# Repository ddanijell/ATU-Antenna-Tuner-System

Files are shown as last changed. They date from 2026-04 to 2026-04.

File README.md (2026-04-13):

# ATU Remote Control System

> HF antenna tuner upgrade — wireless remote control, real-time PWR/SWR telemetry, manual L/C tuning and full touch GUI for ATU100/ATU130.

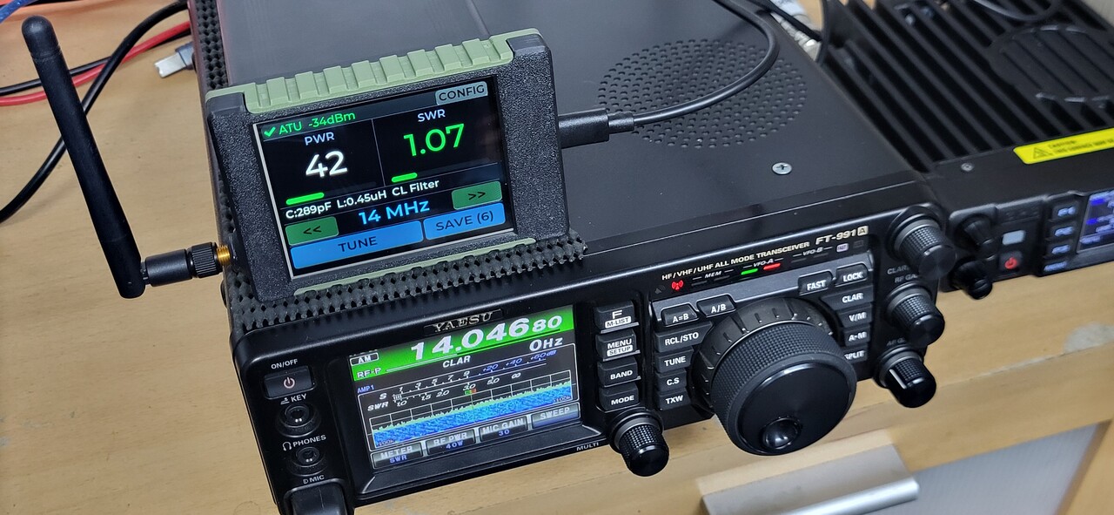
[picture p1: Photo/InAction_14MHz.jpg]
In action — 14 MHz


> More photos available in the [Photo](Photo/) folder.

---

## System Architecture

System block diagram

---

## GUI Screens

| MAIN | CONFIG | BRIGHTNESS | SYSTEM SETTINGS |
|:---:|:---:|:---:|:---:|
|  |  |  |  |

---

## About

This system is an upgrade for the existing [ATU100/ATU130](https://github.com/Dfinitski/N7DDC-ATU-100-mini-and-extended-boards) antenna tuners by N7DDC. In their original form these tuners have no band memory, no manual L/C fine-tuning, no remote control interface and no way to be positioned at the antenna feed point — since in that case there is no control interface and no way to monitor PWR and SWR. This project adds:

- **Wireless remote control** via ESP-NOW
- **Real-time PWR and SWR telemetry** on the display
- **30 memory slots** (11 currently in use — one per amateur band)
- **Full touch GUI** — manual L/C adjustment, relay visualisation, cal parameter editing
- **SD card OTA** firmware update
- **Battery voltage monitoring** — GPIO 35 ADC, 470k/100k divider, shown in status bar
- **PING/PONG keepalive** — link health monitoring every 5 s without UART traffic

---

## Hardware

| Component | Details |
|---|---|
| ATU100 MCU | PIC16F1938 · 32 MHz (8M × 4xPLL) |
| ATU130 MCU | PIC18F2520 · 16 MHz (4M × 4xPLL) |
| UART link (PIC) | 9600 baud · TX=RB7 · RX=RB6 · IOC interrupt · circular buffer |
| EEPROM | 256 bytes · 8 cal params · 30 relay slots (3 bytes each) |
| Transiver MCU | ESP32 |
| UART link (ESP32) | Serial2 · GPIO16=RX · GPIO17=TX · 9600 baud |
| Interface | DC-DC 12V→5V Buck mini · 3V3↔5V level shifter (UART logic level coupling) |
| Pairing | ESP-NOW · NVS MAC persistence · GPIO0 hold >5s to unpair |
| Display MCU | ESP32 CYD · HSPI (pins 12–15) · VSPI SD (pins 18–19,23) |
| Display panel | ST7789 · 3.2″ IPS · 320×240 · backlight PWM GPIO27 |
| Touch controller | XPT2046 · shared HSPI · CS=GPIO33 |
| GUI framework | LVGL 9.2 · Montserrat SemiBold 16/20/24/28 pt |
| Battery monitor | GPIO 35 (ADC1_CH7) · 470 kΩ / 100 kΩ divider · `analogReadMilliVolts()` · shown in status bar |
| Power | 12V DC |

---

## ESP-NOW Protocol

Packet format: `[0xAA][TYPE][payload...]`

| Type | Direction | Payload |
|---|---|---|
| `0x01` `$PWR` | ATU → Display | `power,swr,ind_hex,cap_hex,sw` |
| `0x02` `$CAL` | ATU → Display | all cal params + relay state |
| `0x03` CMD | Display → ATU | command string |
| `0x04` `$TUNE` | ATU → Display | tuning status code (0–15) |
| `0x05` ANN | both | pairing announce, 6-byte MAC |
| `0x06` PING | Display → Transiver | keepalive ping, no payload |
| `0x07` PONG | Transiver → Display | keepalive pong, no payload |

> SWR is transmitted as `int × 100` (e.g., 125 = 1.25).

---

## ATU Commands

| Command | Description |
|---|---|
| `tune\r` | Start autotune |
| `r{slot}\r` | Recall relay slot (1–30) |
| `s{slot}\r` | Save current L/C/SW to slot |
| `L{7bit}\r` | Set inductors (MSB=4.5 µH, LSB=0.05 µH) |
| `C{8bit}\r` | Set capacitors (MSB=1000 pF, LSB=Cap_sw) |
| `reset\r` | All relays off (bypass) |
| `cal\r` | Request calibration data |
| `K/M/D/S/R/W/V/A {val}\r` | Set calibration parameters |

---

## Getting Started

### Requirements

- **ATU100 / ATU130:** MPLAB X IDE, XC8 compiler, PICkit programmer
- **ATU_transiver / ATU_display:** Arduino IDE 2.x, ESP32 board package

### Libraries (ATU_display)

```
LVGL 9.2
TFT_eSPI
XPT2046_Touchscreen
SD (built-in)
```

### Flash Instructions

1. **ATU100 or ATU130** — open `ATU100_NEW/` or `ATU130_NEW/` in MPLAB X, build and flash via PICkit
2. **ATU_transiver** — open `ATU_transiver/ATU_transiver.ino` in Arduino IDE, select board *ESP32 Dev Module*, flash
3. **ATU_display** — open `ATU_display/ATU_display.ino`, select board *ESP32 Dev Module*, flash

### First Boot — Pairing

1. Power on **ATU_transiver** — it broadcasts pairing announcements every 2 s
2. Power on **ATU Display** — it detects the announcement and shows a pairing confirmation dialog; confirm to save the peer MAC to NVS
3. Both devices switch to unicast mode — **pairing complete**
4. To unpair: hold GPIO0 on ATU_transiver for >5 s, or hold the unpair button on the ATU Display for 2 s (both sides unpair simultaneously)

### OTA Firmware Update (ATU Display)

1. Copy new firmware binary as `firmware.bin` to the SD card root
2. Insert SD card and power on the display
3. Update starts automatically with a progress bar on screen
4. On success `firmware.bin` is renamed to `firmware.bak` and the device restarts

---

## File Structure

```
├── ATU100_NEW/              PIC16F1938 firmware
├── ATU130_NEW/              PIC18F2520 firmware (identical logic)
├── ATU_transiver/           ESP32 Serial ↔ ESP-NOW bridge
└── ATU_display/       ESP32 CYD touch display
    ├── ATU_display.ino
    ├── tft_setup.h
    ├── espnow_comm.h
    ├── parsing.h
    ├── gui_screens.h
    ├── gui_update.h
    ├── callbacks.h
    └── ota_update.h
```

---

## 3D Print Housing

STL files for the enclosure are in the `3D_Print_Housing/` folder.

- Material: PLA, 0.2mm layer height, 20% infill
- License: [CC BY-SA 4.0](https://creativecommons.org/licenses/by-sa/4.0/)

---

## Credits

- Original **ATU100/ATU130** project by N7DDC — [github.com/Dfinitski/N7DDC-ATU-100-mini-and-extended-boards](https://github.com/Dfinitski/N7DDC-ATU-100-mini-and-extended-boards)
- Remote operation inspiration — [github.com/edsonbrusque/ATU-100](https://github.com/edsonbrusque/ATU-100)
- Development and testing — **YT1DDL** and **YU4ZED**

---

*HF Ham Radio · PIC + ESP32 · LVGL · ESP-NOW · 2025–2026 · AI-assisted development*

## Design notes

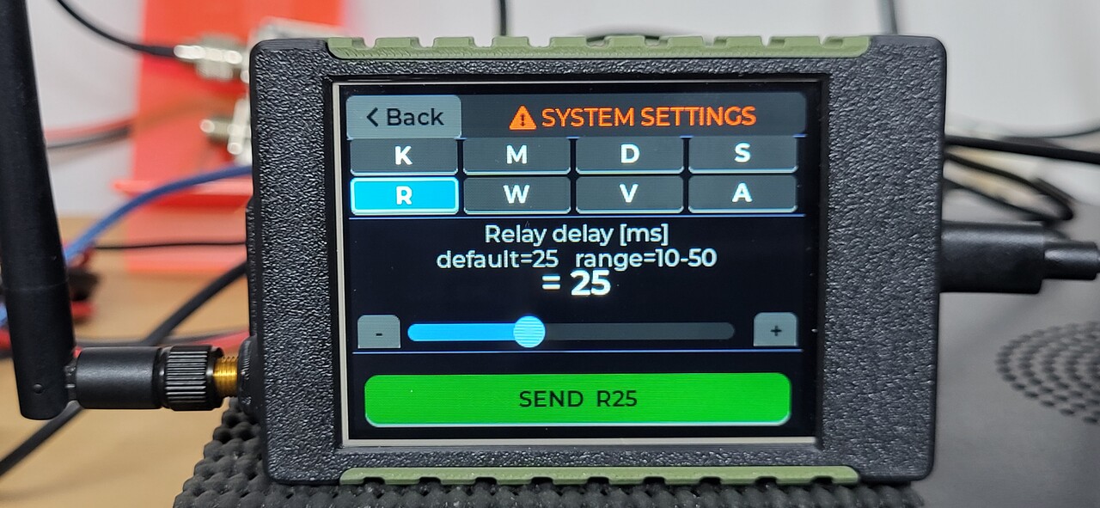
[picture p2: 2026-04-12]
Photo/system_05.jpg

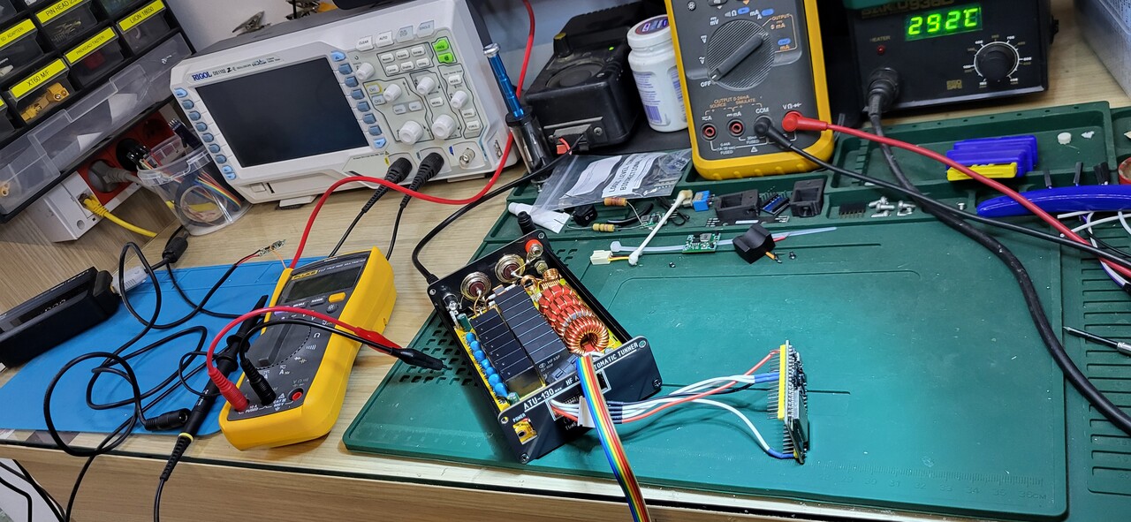
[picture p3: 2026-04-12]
Photo/work_in_progress.jpg

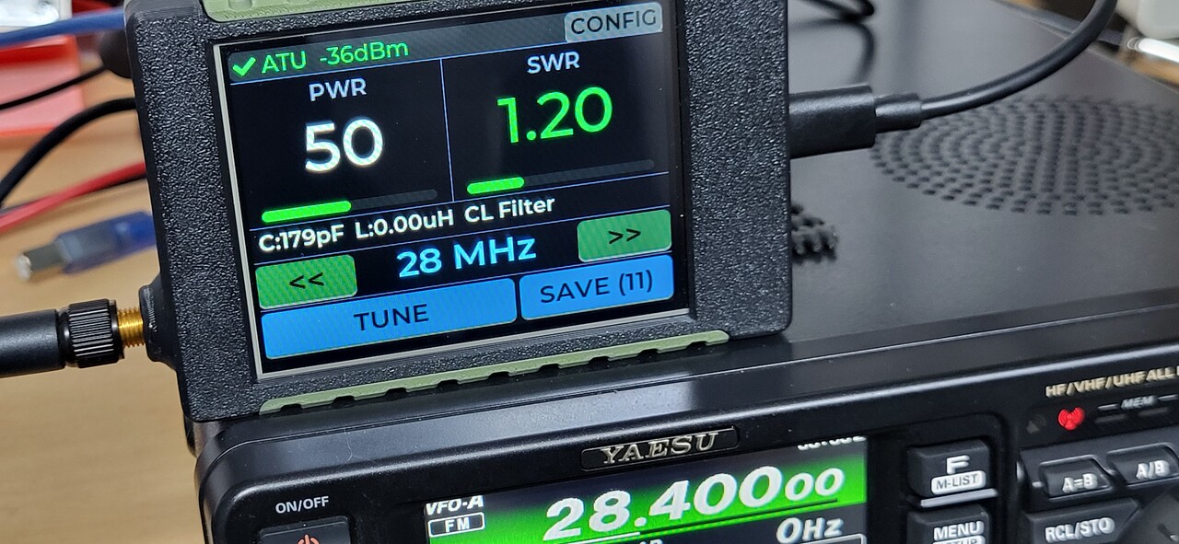
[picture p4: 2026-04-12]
Photo/ATUdisplay_housing.jpg

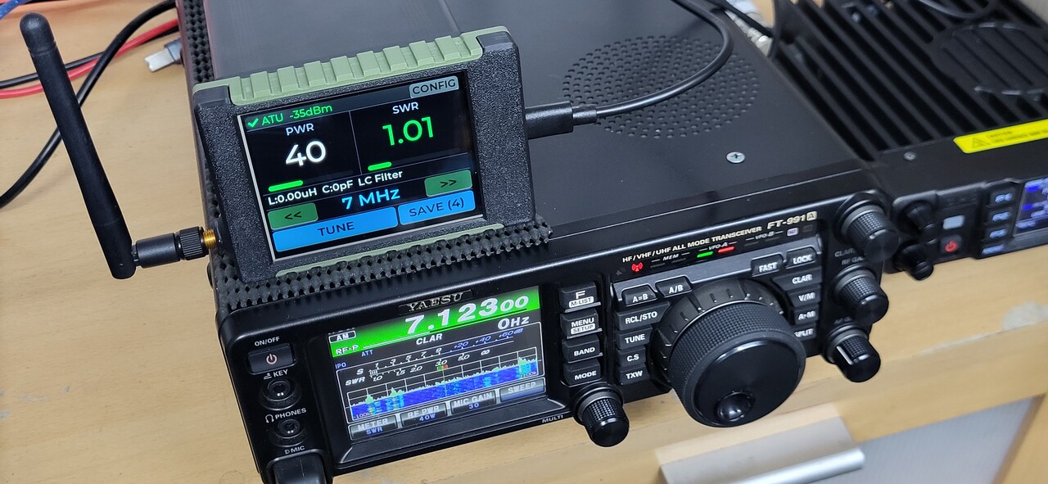
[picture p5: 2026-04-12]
Photo/InAction_7MHz.jpg

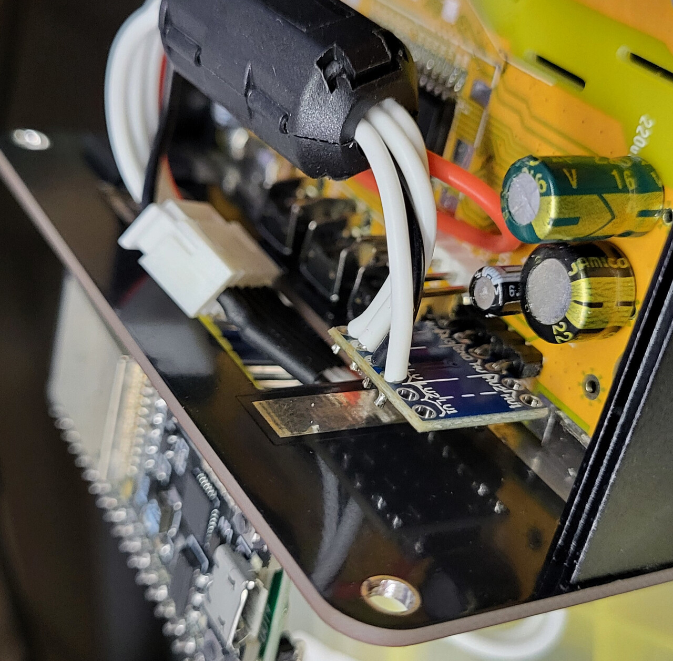
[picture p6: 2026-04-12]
Photo/LeverShifter.jpg

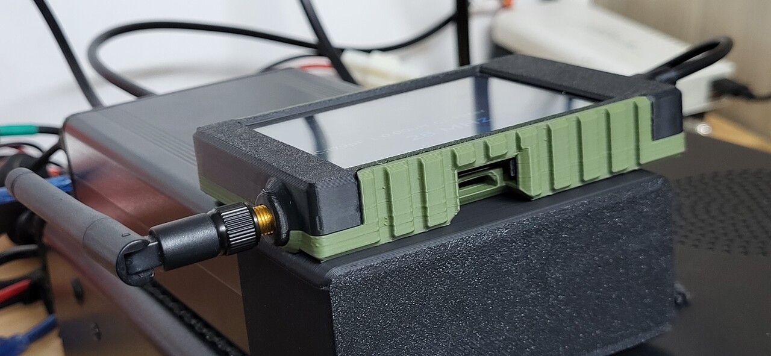
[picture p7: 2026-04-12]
Photo/ATU130_Cover_frontview.jpg

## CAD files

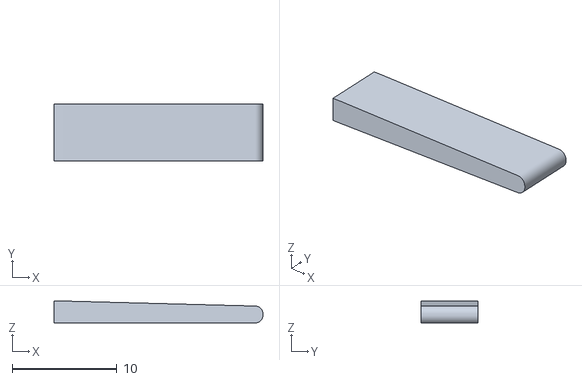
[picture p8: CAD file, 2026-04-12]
3D_Print_Housing/ESP32_bracket_pin.STL
20.0 x 5.50 x 2.10

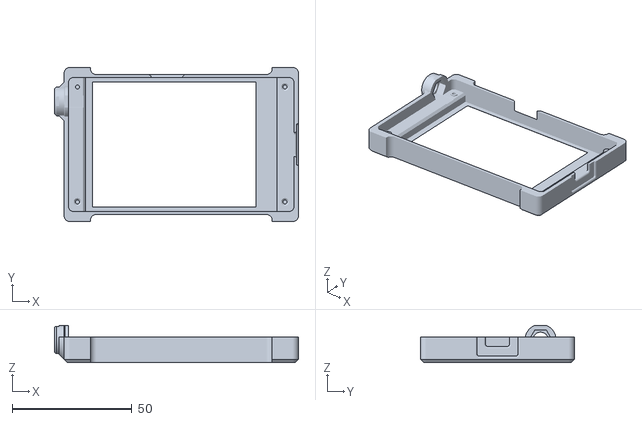
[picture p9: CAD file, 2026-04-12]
3D_Print_Housing/CUD32_front_antenna.STL
102.0 x 64.5 x 15.5

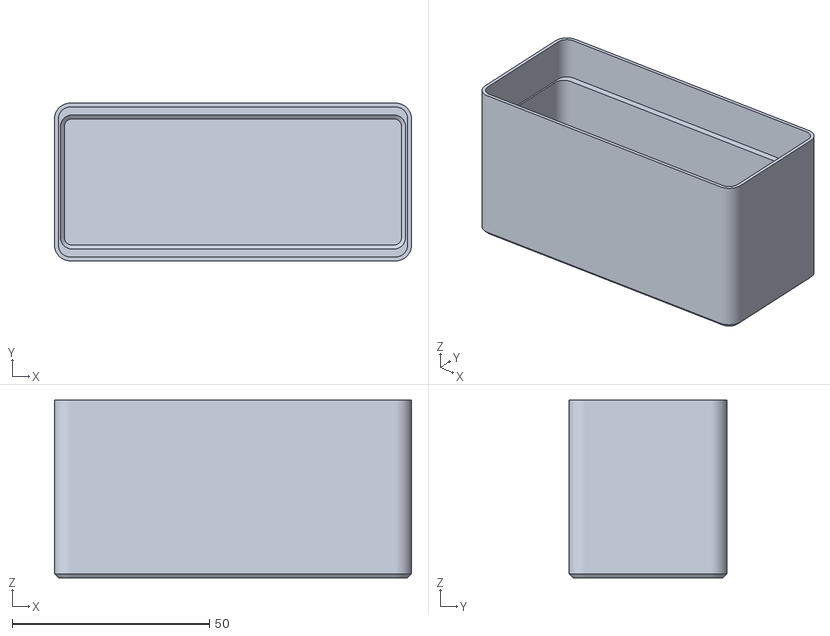
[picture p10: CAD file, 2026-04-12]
3D_Print_Housing/AntTuner_front.STL
90.5 x 40.0 x 45.0

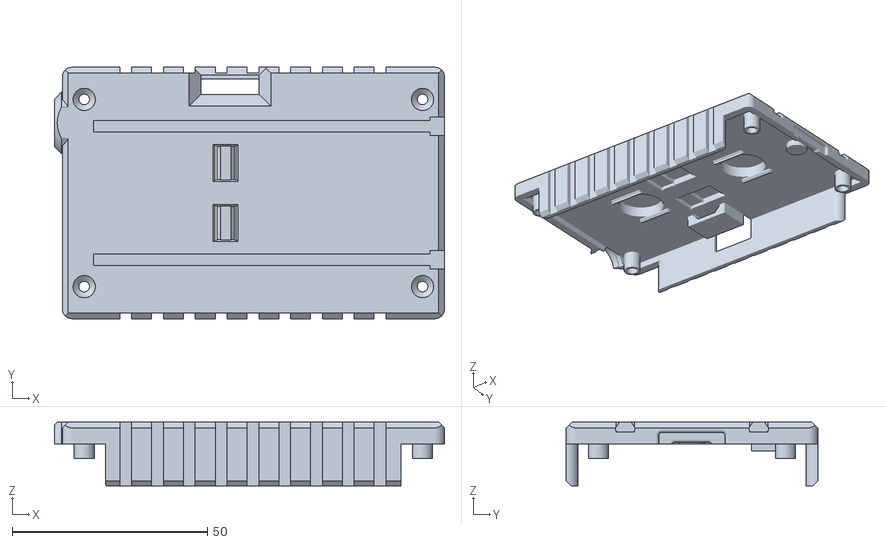
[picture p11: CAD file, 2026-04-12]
3D_Print_Housing/CUD32_back_antenna.STL
100.0 x 64.5 x 16.4

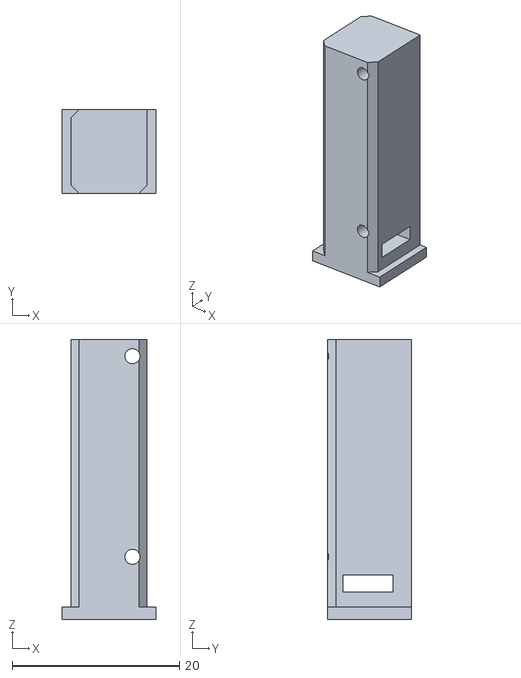
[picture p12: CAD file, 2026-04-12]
3D_Print_Housing/ESP32_module_holder.STL
11.2 x 10.0 x 33.5

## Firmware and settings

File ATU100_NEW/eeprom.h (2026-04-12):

// ATU-100 Project
// eeprom.h - EEPROM kalibracija i perzistentne varijable
//
// PIC16F1938: 256 bajtova EEPROM (adrese 0x00 - 0xFF)
//
// Mapa:
//   0x00  Magic byte (0xAA = inicijalizovan)
//   0x01  K_MULT       - kalibracija tandem match (default 16)
//   0x02  MIN_POWER    - min snaga za tuning u W   (default 5)
//   0x03  DIVIDER      - otpornicki razdelnik, cuva se (val*100 - 100), opseg 1.00-3.55
//   0x04  COARSE_STEP  - korak grube pretrage (default 8, opseg 1-127)
//   0x05  RELAY_MS     - delay nakon preklapanja releja [ms] (default 20)
//   0x06  RETRY_WAIT   - cekanje pri gubitku signala x10ms (default 50 = 500ms)
//   0x07  DEBUG        - verbose serial ispis (default 1 = ukljucen)

#ifndef EEPROM_H
#define EEPROM_H

#include <stdint.h>

// === EEPROM ADRESE ===
#define EE_MAGIC        0x00
#define EE_K_MULT       0x01
#define EE_MIN_POWER    0x02
#define EE_DIVIDER      0x03
#define EE_COARSE_STEP  0x04
#define EE_RELAY_MS     0x05
#define EE_RETRY_WAIT   0x06
#define EE_DEBUG        0x07
#define EE_ADC_SWAP     0x08    // swap ADC kanala: 0=fwd AN0/rev AN1, 1=fwd AN1/rev AN0
#define EE_LAST_SLOT    0x09    // poslednji aktivni slot (1-30)
// 0x0A-0x9F: rezerva za buduće parametre
#define EE_CONFIG_BASE  0xA0    // baza za 30 konfiguracija releja
#define EE_CONFIG_MAX   30      // maks broj konfiguracija

// === FACTORY DEFAULTS ===
#define EE_MAGIC_VAL        0xAA
#define DEFAULT_K_MULT      10
#define DEFAULT_MIN_POWER   5
#define DEFAULT_DIVIDER     205     // (3.05*100) - 100 = 205, stvarna vrijednost 3.05
#define DEFAULT_COARSE_STEP 8       // korak grube pretrage (opseg 1-127)
#define DEFAULT_RELAY_MS    25      // relay settling time [ms]
#define DEFAULT_RETRY_WAIT  50      // cekanje pri gubitku signala x10ms (50=500ms)
#define DEFAULT_DEBUG       1       // verbose serial ispis (1=ukljucen)
#define DEFAULT_ADC_SWAP    0       // 0=fwd AN0/rev AN1, 1=fwd AN1/rev AN0
#define DEFAULT_LAST_SLOT   1       // default slot pri prvom boot-u

// === RUNTIME KALIBRACIJSKE VARIJABLE ===
// Punjene iz EEPROM-a pri boot-u via eeprom_init()
extern uint8_t cal_K_mult;
extern uint8_t cal_min_power;
extern uint8_t cal_divider_x100;   // razdelnik offset: stvarna = (val+100)/100.0 (34=1.34, 200=3.00)
extern uint8_t cal_coarse_step;    // korak grube pretrage autotune
extern uint8_t cal_relay_ms;       // delay nakon preklapanja releja [ms]
extern uint8_t cal_retry_wait;     // cekanje pri gubitku signala x10ms
extern uint8_t cal_debug;          // verbose serial ispis (1=ukljucen)
extern uint8_t cal_adc_swap;       // swap ADC kanala (0=default, 1=swap)
extern uint8_t cal_last_slot;      // poslednji aktivni slot (1-30)

// === API ===
uint8_t ee_read(uint8_t addr);
void    ee_write(uint8_t addr, uint8_t data);
void    eeprom_init(void);
void    cal_load(void);
void    cal_save(void);
void    cal_print(void);
void    cal_print_struct(void);
void    relay_config_save(uint8_t n);    // snimi L/C/SW u slot n (1-30)
void    relay_config_recall(uint8_t n);  // ucitaj L/C/SW iz slota n (1-30)
void    eeprom_factory_reset(void);      // obrisi magic byte -> defaults pri sljedecem boot-u

#endif // EEPROM_H

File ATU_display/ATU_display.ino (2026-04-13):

// ATU_display
// ESP32 CYD (Cheap Yellow Display) 240x320 - ATU front-end GUI
//
// Ekran 1 (Main):    PWR/SWR + relay + band info + [TUNE][Band-][Band+][CONFIG]
// Ekran 2 (Config):  CAL + [L-][L+][C-][C+] + [SW][RESET][REBOOT][SAVE] + [BACK][Next>]
// Ekran 3 (Bright):  Brightness slider + [BACK]
//
// ESP-NOW protokol (isti kao ATU_transiver):
//   [0xAA][TYPE][poruka]
//   TYPE: 0x01=$PWR, 0x02=$CAL, 0x03=CMD, 0x04=$TUNE, 0x05=ANN
//
// Biblioteke: lvgl 9.2, TFT_eSPI, XPT2046_Touchscreen

#define APP_VERSION  "v1.04"

#include <Arduino.h>
#include <lvgl.h>
#include <TFT_eSPI.h>
#include <XPT2046_Touchscreen.h>
#include <esp_now.h>
#include <WiFi.h>
#include <esp_wifi.h>
#include <Preferences.h>
#include "driver/ledc.h"
#include <SPI.h>
#include <SD.h>
    //#define LV_USE_FONT_COMPRESSION 1
    LV_FONT_DECLARE(lv_font_montserrat_sb_16);
    LV_FONT_DECLARE(lv_font_montserrat_sb_20);
    LV_FONT_DECLARE(lv_font_montserrat_sb_24);
    LV_FONT_DECLARE(lv_font_montserrat_sb_28);



// ============================================================
// CYD PINOUT - definisan u tft_setup.h (BL_PIN, XPT2046_*, CYD_SHARED_SPI)
// ============================================================



// Baterija
#define BAT_PIN         35   // ADC1_CH7, input-only, deljac 470k/100k

// SD kartica
#define SD_MOSI         23
#define SD_MISO         19
#define SD_CLK          18
#define SD_CS           5
static SPIClass sdSPI(VSPI);   // VSPI - sekvencijalno sa touchscreenom, nema konflikta sa TFT/HSPI
#define LEDC_CH         LEDC_CHANNEL_0
#define LEDC_TIM        LEDC_TIMER_0
#define LEDC_FREQ       5000
#define LEDC_RES        LEDC_TIMER_8_BIT
#define SCREEN_WIDTH    240
#define SCREEN_HEIGHT   320

// ============================================================
// ESP-NOW
// ============================================================
#define ESPNOW_MAGIC     0xAA
#define ESPNOW_TYPE_PWR  0x01
#define ESPNOW_TYPE_CAL  0x02
#define ESPNOW_TYPE_CMD  0x03
#define ESPNOW_TYPE_TUNE 0x04
#define ESPNOW_TYPE_ANN  0x05    // Announce/pairing: payload = 6-byte MAC
#define ESPNOW_TYPE_PING 0x06    // Ping: Display -> Transiver (no payload)
#define ESPNOW_TYPE_PONG 0x07    // Pong: Transiver -> Display (no payload)
#define ESPNOW_CHANNEL   14
static uint8_t broadcast_mac[] = { 0xFF,0xFF,0xFF,0xFF,0xFF,0xFF };

// === PAIRING STATE ===
static uint8_t  paired_mac[6]    = {0};
static bool     is_paired         = false;
static Preferences prefs;
#define NVS_NS      "atapair"
#define NVS_KEY_MAC "mac"

// Pending pairing request waiting for user confirmation
static volatile bool pair_request   = false;
static uint8_t       pair_req_mac[6] = {0};

// ============================================================
// Bandovi (11 amatersih opsega)
// ============================================================
struct Band { const char *label; uint8_t slot; };
static const Band bands[] = {
    {"1.8 MHz", 1}, {"3.5 MHz", 2}, {"5 MHz",  3},
    {"7 MHz",   4}, {"10 MHz",  5}, {"14 MHz", 6},
    {"18 MHz",  7}, {"21 MHz",  8}, {"25 MHz", 9},
    {"27 MHz", 10}, {"28 MHz", 11}
};
#define BAND_COUNT 11
static uint8_t g_band = 5;   // default: 14MHz (index 5)

// ============================================================
// CAL parametri za editovanje (screen4)
// ============================================================
struct CalParam {
    const char *label;    // kratko ime za dugme
    const char *desc;     // pun naziv
    char        cmd;      // slovo komande (K, M, D, S, R, W, V, A)
    int         min_val;
    int         max_val;
    bool        is_bool;
};
static const CalParam cal_params[] = {
    { "K", "K_MULT calibration\ndefault=16   range=1-255",        'K', 1,    255,  false },
    { "M", "Minimum power for tuning [W]\ndefault=5    range=1-20",    'M', 1,    20,   false },
    { "D", "ADC divider ratio\nrange 1.00-3.55",                      'D', 100,  355,  false },
    { "S", "Coarse search step\ndefault=8    range=1-32", 'S', 1,    32,   false },
    { "R", "Relay delay [ms]\ndefault=25   range=10-50",'R', 10,   50,   false },
    { "W", "Wait for PWR to continue\ndefault=500ms  range=100-1000ms",         'W', 100,  1000, false },
    { "V", "Debug output OFF / ON\ndefault=1",                     'V', 0,    1,    true  },
    { "A", "ADC input swap OFF / ON\ndefault=0",                        'A', 0,    1,    true  },
};
#define CAL_PARAM_COUNT 8

// ============================================================
// Podaci
// ============================================================
struct PwrData { uint16_t pwr, swr; uint8_t ind, cap, sw; bool overload; };
struct CalData {
    uint8_t k_mult, min_pwr, coarse_step, relay_ms, retry_wait, debug, adc_swap;
    uint16_t div;       // x100
    uint8_t last_slot;  // poslednji aktivni slot (1-30)
    uint8_t ind, cap, sw; // trenutno stanje releja iz ATU
};
static PwrData  g_pwr       = {0, 999, 0, 0, 0, false};
static CalData  g_cal       = {};
static bool     g_cal_valid = false;
static uint32_t last_rx_ms  = 0;   // zadnji primljeni paket
static uint32_t last_hb_ms  = 0;   // zadnji heartbeat poslan
#define CONNECTED_TIMEOUT_MS  15000
#define HEARTBEAT_MS          30000

// Thread-safe bufer
static volatile bool new_pwr = false, new_cal = false, new_tune = false;
static char pwr_buf[64], cal_buf[64], tune_buf[12];

// Zadnje validne vrijednosti PWR/SWR (za prikaz kad padne na 0)
static uint16_t g_last_valid_pwr = 0;
static uint16_t g_last_valid_swr = 999;

// ESP-NOW signal strength (RSSI zadnjeg paketa)
static int8_t g_rssi = 0;

// SAVE potvrda
static bool     g_save_pending   = false;
static uint32_t g_save_ms        = 0;
#define SAVE_TIMEOUT_MS  3000

// Nakon RESET komande: pošalji cal nakon kratke pauze
static uint32_t g_reset_cal_ms   = 0;   // != 0 kad čekamo na cal refresh
#define RESET_CAL_DELAY_MS  1000        // 1s nakon reset

// $TUNE status
static uint8_t  g_tune_status    = 0;
static uint32_t g_tune_done_ms   = 0;   // timestamp kad je stigao finalni status
#define TUNE_CLEAR_MS  5000             // 5s pa reset na "TUNE"
static const char* const tune_labels[] = {
    "TUNE",       // 0 - idle
    "WAIT PWR",   // 1
    "TUNING...",  // 2
    "RETRY",      // 3
    "COARSE",     // 4
    "SCAP",       // 5
    "SIND",       // 6
    "SW1",        // 7
    "SW2",        // 8
    "SW1 BETTER", // 9
    "SW2 BETTER", // 10
    "FINE",       // 11
    "TUNE OK",    // 12
    "DONE",       // 13
    "ABORT",      // 14
    "SKIP"        // 15
};

// ============================================================
// Brightness
// ============================================================
static int g_brightness = 180;
static void bl_init(void) {
    ledc_timer_config_t t = { .speed_mode=LEDC_LOW_SPEED_MODE,
        .duty_resolution=LEDC_RES, .timer_num=LEDC_TIM,
        .freq_hz=LEDC_FREQ, .clk_cfg=LEDC_AUTO_CLK };
    ledc_timer_config(&t);
    ledc_channel_config_t ch = { .gpio_num=BL_PIN,
        .speed_mode=LEDC_LOW_SPEED_MODE, .channel=LEDC_CH,
        .timer_sel=LEDC_TIM, .duty=0, .hpoint=0,
        .flags={.output_invert=0} };
    ledc_channel_config(&ch);
}
static float read_bat_voltage(void) {
    uint32_t sum = 0;
    for (int i = 0; i < 16; i++) sum += analogReadMilliVolts(BAT_PIN);
    float v_pin_mv = sum / 16.0f;
    return v_pin_mv * 5.7f / 1000.0f;  // mV->V, deljac 470k/100k, faktor 5.7
}

static void bl_set(int v) {
    v = v < 0 ? 0 : v > 255 ? 255 : v;
    g_brightness = v;
    ledc_set_duty(LEDC_LOW_SPEED_MODE, LEDC_CH, v);
    ledc_update_duty(LEDC_LOW_SPEED_MODE, LEDC_CH);
}

// ============================================================
// LVGL ekrani i objekti
// ============================================================
static lv_obj_t *scr_main;
static lv_obj_t *scr_config;
static lv_obj_t *scr_bright;
static lv_obj_t *scr_cal_edit;

// --- Main screen objekti ---
static lv_obj_t *lbl_status;
static lv_obj_t *lbl_ovr;
static lv_obj_t *lbl_pwr_val;
static lv_obj_t *lbl_swr_val;
static lv_obj_t *bar_pwr;
static lv_obj_t *bar_swr;
static lv_obj_t *lbl_relay;
static lv_obj_t *lbl_band_freq;
static lv_obj_t *lbl_bat;

// --- Main screen - TUNE dugme label ---
static lv_obj_t *lbl_tune_btn;

// --- Config screen objekti ---
static lv_obj_t *lbl_cfg_status;   // status u headeru bright screena (screen3)
static lv_obj_t *lbl_cfg_status2;  // status u headeru config screena (screen2)
static lv_obj_t *slider_brt;
static lv_obj_t *slider_l_direct = NULL;
static lv_obj_t *slider_c_direct = NULL;
static lv_obj_t *lbl_bypass_btn  = NULL;
static bool      g_bypass_active  = false;
static uint8_t   g_saved_ind = 0, g_saved_cap = 0, g_saved_sw = 0;
static lv_obj_t *lbl_l_val;       // trenutna L vrijednost (npr. "0.67 uH")
static lv_obj_t *lbl_c_val;       // trenutna C vrijednost (npr. "870 pF")
static lv_obj_t *btn_sw;          // SW toggle dugme
static lv_obj_t *lbl_sw_state;    // label unutar SW dugmeta ("SW0" / "SW1")
static lv_obj_t *lbl_save_btn;    // label unutar SAVE dugmeta (dinamicki slot)
static lv_obj_t *lbl_unpair_btn;  // label unutar UNPAIR dugmeta (dinamicki)
// --- CAL edit screen objekti ---
static lv_obj_t *lbl_cedit_name;
static lv_obj_t *lbl_cedit_val;
static lv_obj_t *slider_cedit;
static lv_obj_t *lbl_cedit_send;
static lv_obj_t *cedit_slider_row;   // kontejner slider + fine buttons (sakrij za bool)
static lv_obj_t *cedit_toggle_row;   // kontejner toggle dugmeta (za bool)
static lv_obj_t *lbl_cedit_toggle;
static lv_obj_t *param_btns[CAL_PARAM_COUNT];
static uint8_t   g_cedit_idx = 0;
static int       g_cedit_val = 0;
static lv_obj_t *pair_dialog = NULL;  // overlay pairing dialog

// ============================================================
// Touchscreen
// ============================================================
#ifdef CYD_SHARED_SPI
SPIClass touchscreenSPI(HSPI);   // dijeli HSPI sa TFT, razlicit CS
#else
SPIClass touchscreenSPI(VSPI);   // odvojen VSPI, razliciti pinovi
#endif
XPT2046_Touchscreen touchscreen(XPT2046_CS, XPT2046_IRQ);
#define DRAW_BUF_SIZE (SCREEN_WIDTH * SCREEN_HEIGHT / 10 * (LV_COLOR_DEPTH / 8))
static uint32_t draw_buf[DRAW_BUF_SIZE / 4];
static void touchscreen_read(lv_indev_t*, lv_indev_data_t *data) {
    if (touchscreen.tirqTouched() && touchscreen.touched()) {
        TS_Point p = touchscreen.getPoint();
#ifdef CYD_TOUCH_MIRROR_X
        int16_t x = (int16_t)map(p.x, TOUCH_X_MAX, TOUCH_X_MIN, 0, SCREEN_WIDTH  - 1);
#else
        int16_t x = (int16_t)map(p.x, TOUCH_X_MIN, TOUCH_X_MAX, 0, SCREEN_WIDTH  - 1);
#endif
#ifdef CYD_TOUCH_MIRROR_Y
        int16_t y = (int16_t)map(p.y, TOUCH_Y_MAX, TOUCH_Y_MIN, 0, SCREEN_HEIGHT - 1);
#else
        int16_t y = (int16_t)map(p.y, TOUCH_Y_MIN, TOUCH_Y_MAX, 0, SCREEN_HEIGHT - 1);
#endif


        if (x < 0) x = 0; if (x > SCREEN_WIDTH  - 1) x = SCREEN_WIDTH  - 1;
        if (y < 0) y = 0; if (y > SCREEN_HEIGHT - 1) y = SCREEN_HEIGHT - 1;
        data->point.x = x;
        data->point.y = y;
        data->state   = LV_INDEV_STATE_PRESSED;
    } else {
        data->state = LV_INDEV_STATE_RELEASED;
    }
}

#include "parsing.h"
#include "espnow_comm.h"
#include "gui_update.h"
#include "callbacks.h"
#include "gui_screens.h"
#include "ota_update.h"

// ============================================================
void setup() {
    Serial.begin(115200);
    Serial.println("\n[ATU_display_SD] boot " APP_VERSION);

    // --- SD kartica init (VSPI - sekvencijalno sa touchscreenom, nema konflikta sa TFT/HSPI) ---
    sdSPI.begin(SD_CLK, SD_MISO, SD_MOSI, SD_CS);
    if (!SD.begin(SD_CS, sdSPI)) {
        Serial.println("[SD] Mount FAIL - nema kartice ili greska");
    } else {
        Serial.printf("[SD] Mount OK  - velicina: %llu MB\n", SD.cardSize() / (1024 * 1024));
        if (SD.exists("/firmware.bin")) {
            Serial.println("[SD] firmware.bin PRONADJEN - startujem OTA prompt");
        } else {
            Serial.println("[SD] firmware.bin nije pronadjen");
        }
        check_and_ota();  // prikazuje prompt i radi update ako korisnik potvrdi
    }

    lv_init();
    touchscreenSPI.begin(XPT2046_CLK, XPT2046_MISO, XPT2046_MOSI, XPT2046_CS);
    touchscreen.begin(touchscreenSPI);
    touchscreen.setRotation(2);

    lv_display_t *disp = lv_tft_espi_create(SCREEN_WIDTH, SCREEN_HEIGHT,
                                             draw_buf, sizeof(draw_buf));
    lv_display_set_rotation(disp, LV_DISPLAY_ROTATION_90);

    lv_indev_t *indev = lv_indev_create();
    lv_indev_set_type(indev, LV_INDEV_TYPE_POINTER);
    lv_indev_set_read_cb(indev, touchscreen_read);

    bl_init();
    g_brightness = nvs_load_brightness(g_brightness);
    bl_set(g_brightness);

    create_main_screen();
    create_config_screen();
    create_bright_screen();
    create_cal_edit_screen();
    lv_screen_load(scr_main);

    espnow_init();
    gui_update_pair_btn();  // osvjezi nakon sto espnow_init ucita NVS
    gui_update_bat();       // prvi ocitaj baterije odmah pri startu
    delay(500);
    send_cmd("V0\r");
    delay(200);
    send_cmd("cal\r");
}

// ============================================================
void loop() {
    uint32_t now = millis();

    // Obrada novih podataka
    if (new_pwr) {
        new_pwr = false;
        parse_pwr(pwr_buf);
        gui_update_pwr();
        gui_update_status();
        g_save_pending = false;
    }
    if (new_cal) {
        new_cal = false;
        parse_cal(cal_buf);
        gui_update_cal();
        gui_update_band();
        gui_update_pwr();
        gui_update_status();
    }
    if (new_tune) {
        new_tune = false;
        // parse "$TUNE:xx"
        const char *p = tune_buf;
        while (*p && *p != ':') p++;
        if (*p == ':') {
            p++;
            uint8_t n = 0;
            while (*p >= '0' && *p <= '9') { n = n*10 + (*p-'0'); p++; }
            g_tune_status = (n < 16) ? n : 0;
            gui_update_tune_btn();
            // finalni statusi: OK(12), DONE(13), ABORT(14), SKIP(15)
            if (g_tune_status >= 12) { g_tune_done_ms = millis(); bypass_cancel(); }
            else                       g_tune_done_ms = 0;
        }
    }

    // --- Pairing request: prikazi dialog ako je stigao ANN ---
    if (pair_request) {
        pair_request = false;
        show_pair_dialog(pair_req_mac);
    }

    // Heartbeat: ako nema podataka 30s, pošalji cal
    if (last_hb_ms == 0 || (now - last_rx_ms > HEARTBEAT_MS &&
                             now - last_hb_ms  > HEARTBEAT_MS)) {
        last_hb_ms = now;
        send_cmd("cal\r");
        g_last_valid_pwr = 0;
        g_last_valid_swr = 999;
        gui_update_pwr();
    }

    // cal refresh nakon RESET komande (1s delay da ATU završi reset)
    if (g_reset_cal_ms != 0 && (now - g_reset_cal_ms) >= RESET_CAL_DELAY_MS) {
        g_reset_cal_ms = 0;
        send_cmd("cal\r");
    }

    // Reset TUNE dugmeta na "TUNE" nakon 5s od finalnog statusa
    if (g_tune_done_ms != 0 && (now - g_tune_done_ms) >= TUNE_CLEAR_MS) {
        g_tune_done_ms = 0;
        g_tune_status  = 0;
        gui_update_tune_btn();
    }

    // Provjeri connection status svakih 2s
    static uint32_t prev_status = 0;
    if (now - prev_status > 2000) {
        prev_status = now;
        gui_update_status();
    }

    // Ocitaj napon baterije svakih 10s
    static uint32_t prev_bat = 0;
    if (now - prev_bat > 10000) {
        prev_bat = now;
        gui_update_bat();
    }

    // PING svakih 5s za monitoring konekcije
    static uint32_t prev_ping = 0;
    if (is_paired && (now - prev_ping > 5000)) {
        prev_ping = now;
        send_ping();
    }



    lv_task_handler();
    lv_tick_inc(5);
    delay(5);
}

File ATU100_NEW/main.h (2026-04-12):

// ATU-100 Project
// PIC16F1938
// main.h - Pin definitions and function prototypes
//
// Oscillator: 8 MHz HFINTOSC + 4xPLL = 32 MHz Fosc
// Fcpu = Fosc/4 = 8 MHz

#ifndef MAIN_H
#define MAIN_H

#include <xc.h>
#include <stdint.h>
#include <stdbool.h>

// === OSCILLATOR ===
#define _XTAL_FREQ      32000000UL

// === UART ===
#define UART_BIT_US     104         // bit period za 9600 baud (1/9600 = 104.17 us)
#define RX_BUF_SIZE     32          // RX kružni bafer, mora biti stepen broja 2

// === UART PINOVI ===
// TX: RB7 - LATBbits.LATB7
// RX: RB6 - PORTBbits.RB6 (IOC, IOCBN6)
#define UART_OUT_PIN    LATBbits.LATB7
#define UART_OUT_TRIS   TRISBbits.TRISB7
#define UART_IN_PIN     PORTBbits.RB6
#define UART_IN_TRIS    TRISBbits.TRISB6

// === I/O PINOVI iz pinout.txt ===

// Pin 1:  Relej - Referenca (Cap switch)
#define Cap_sw      LATCbits.LATC0

// Pin 2-8: Kondenzatori pojedinacno
#define Cap_10      LATCbits.LATC7
#define Cap_22      LATCbits.LATC3
#define Cap_47      LATCbits.LATC6
#define Cap_100     LATCbits.LATC2
#define Cap_220     LATCbits.LATC5
#define Cap_470     LATCbits.LATC1
#define Cap_1000    LATCbits.LATC4

// Pin 9-15: Induktivnosti pojedinacno
#define Ind_005     LATBbits.LATB3
#define Ind_011     LATAbits.LATA2
#define Ind_022     LATBbits.LATB4
#define Ind_045     LATAbits.LATA3
#define Ind_1       LATBbits.LATB5
#define Ind_22      LATAbits.LATA5
#define Ind_45      LATAbits.LATA4

// === DEBUG MACRO ===
// Koristi cal_debug iz eeprom.h (extern uint8_t cal_debug)
#define DBG(s) do { if (cal_debug) uart_print(s); } while(0)

// === PROTOTIPI FUNKCIJA ===
void pic_init(void);

#include "uart.h"
#include "selftest.h"
#include "adc.h"
#include "eeprom.h"
#include "autotune.h"

#endif // MAIN_H

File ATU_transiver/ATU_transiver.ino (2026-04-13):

// ATU_transiver
// ESP32 Serial <-> ESP-NOW bridge
//
// Serial2 (GPIO16=RX, GPIO17=TX, 9600 baud) <-> ESP-NOW
// Serial  (UART0, 115200) -> debug + unos komandi
//
// ATU poruke pocinju sa '$', zavrsavaju sa '\n'
// ESP-NOW paket:
//   Byte 0: MAGIC (0xAA)
//   Byte 1: TYPE  (0x01=$PWR, 0x02=$CAL, 0x03=CMD, 0x04=$TUNE, 0x05=ANN)
//   Byte 2+: originalna poruka (ili 6-byte MAC za ANN)
//
// Pairing:
//   - Boot bez NVS MAC -> broadcast ANNOUNCE svake 2s
//   - Display reply (TYPE_ANN) -> sačuvaj MAC u NVS, unicast od tada
//   - GPIO0 držati >5s -> brisanje NVS MAC, reboot, nova announce faza

#include <Arduino.h>
#include <esp_now.h>
#include <esp_wifi.h>
#include <WiFi.h>
#include <Preferences.h>

// === KONFIGURACIJA ===
#define ATU_SERIAL          Serial2
#define ATU_BAUD            9600
#define ATU_RX_PIN          16
#define ATU_TX_PIN          17

#define DBG_SERIAL          Serial
#define DBG_BAUD            115200

#define MSG_BUF_SIZE        64      // max duzina jedne ATU poruke

#define GPIO_UNPAIR_PIN     0       // GPIO0 = BOOT button
#define UNPAIR_HOLD_MS      5000    // 5s drzanje za unpair

// === ESP-NOW ===
#define ESPNOW_MAGIC        0xAA
#define ESPNOW_TYPE_PWR     0x01    // $PWR:...
#define ESPNOW_TYPE_CAL     0x02    // $CAL:...
#define ESPNOW_TYPE_CMD     0x03    // komanda prema ATU
#define ESPNOW_TYPE_TUNE    0x04    // $TUNE:x
#define ESPNOW_TYPE_ANN     0x05    // Announce/pairing: payload = 6-byte MAC
#define ESPNOW_TYPE_PING    0x06    // Ping: Display -> Transiver (no payload)
#define ESPNOW_TYPE_PONG    0x07    // Pong: Transiver -> Display (no payload)
#define ESPNOW_TYPE_OTHER   0x00

// Broadcast MAC
static uint8_t broadcast_mac[] = { 0xFF, 0xFF, 0xFF, 0xFF, 0xFF, 0xFF };

// === PAIRING STATE ===
static uint8_t  paired_mac[6]  = {0};
static bool     is_paired       = false;

static Preferences prefs;
#define NVS_NS      "atapair"
#define NVS_KEY_MAC "mac"

// === ANNOUNCE TIMER ===
#define ESPNOW_CHANNEL        14
#define ANNOUNCE_INTERVAL_MS  2000
#define ANNOUNCE_TIMEOUT_MS   120000   // 2 minute max, pa prestaje
static uint32_t last_ann_ms   = 0;
static uint32_t ann_start_ms  = 0;     // kad je krenuo announce (0 = nije aktivan)
static bool     ann_active    = false;

// === ATU SERIAL RX BAFER ===
static char     atu_rx_buf[MSG_BUF_SIZE];
static uint8_t  atu_rx_len    = 0;
static bool     atu_rx_active = false;

// === DBG SERIAL RX BAFER ===
static char     dbg_rx_buf[MSG_BUF_SIZE];
static uint8_t  dbg_rx_len = 0;

// ============================================================
// NVS: load / save / clear
// ============================================================
static bool nvs_load_mac(uint8_t *mac) {
    prefs.begin(NVS_NS, true);  // read-only
    size_t len = prefs.getBytes(NVS_KEY_MAC, mac, 6);
    prefs.end();
    if (len != 6) return false;
    // provjeri da nije sve nule (ocisceno)
    for (int i = 0; i < 6; i++) if (mac[i] != 0x00) return true;
    return false;
}

static void nvs_save_mac(const uint8_t *mac) {
    prefs.begin(NVS_NS, false);
    prefs.putBytes(NVS_KEY_MAC, mac, 6);
    prefs.end();
}

static void nvs_clear_mac(void) {
    prefs.begin(NVS_NS, false);
    prefs.remove(NVS_KEY_MAC);
    prefs.end();
}

// ============================================================
// Dodaje unicast peer (display MAC)
// ============================================================
static void add_unicast_peer(const uint8_t *mac) {
    if (esp_now_is_peer_exist(mac)) return;
    esp_now_peer_info_t peer = {};
    memcpy(peer.peer_addr, mac, 6);
    peer.channel = ESPNOW_CHANNEL;
    peer.encrypt = false;
    esp_now_add_peer(&peer);
}

// ============================================================
// Salje PONG unicast na display
// ============================================================
static void send_pong(const uint8_t *dest_mac) {
    uint8_t pkt[2] = { ESPNOW_MAGIC, ESPNOW_TYPE_PONG };
    esp_now_send(dest_mac, pkt, 2);
}

// ============================================================
// Salje ANNOUNCE broadcast (vlastiti MAC kao payload)
// ============================================================
static void send_announce(void) {
    uint8_t pkt[8];
    pkt[0] = ESPNOW_MAGIC;
    pkt[1] = ESPNOW_TYPE_ANN;
    // payload: vlastiti MAC (6 bajtova)
    uint8_t own_mac[6];
    esp_wifi_get_mac(WIFI_IF_STA, own_mac);
    memcpy(&pkt[2], own_mac, 6);

    esp_now_send(broadcast_mac, pkt, 8);
    DBG_SERIAL.println("[ANN] Announce broadcast sent, waiting for display...");
}

// ============================================================
// Odredjuje TYPE byte na osnovu sadrzaja ATU poruke
// ============================================================
static uint8_t detect_type(const char *msg) {
    if (msg[1] == 'P' && msg[2] == 'W' && msg[3] == 'R') return ESPNOW_TYPE_PWR;
    if (msg[1] == 'C' && msg[2] == 'A' && msg[3] == 'L') return ESPNOW_TYPE_CAL;
    if (msg[1] == 'T' && msg[2] == 'U' && msg[3] == 'N' && msg[4] == 'E') return ESPNOW_TYPE_TUNE;
    return ESPNOW_TYPE_OTHER;
}

// ============================================================
// ESP-NOW send callback
// ============================================================
static void on_data_sent(const uint8_t *mac, esp_now_send_status_t status) {
    // DBG_SERIAL.printf("[TX] %s\n", status == ESP_NOW_SEND_SUCCESS ? "OK" : "FAIL");
}
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

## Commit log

2026-04-12 Initial commit: ATU antenna tuner system v1.0
    [AntTuner_front.STL, CUD32_back_antenna.STL, CUD32_front_antenna.STL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]
2026-04-12 Fix ESP-NOW label position in block diagram — move above WiFi icon
2026-04-13 Add battery voltage monitor and ESP-NOW PING/PONG keepalive
    - Battery voltage on GPIO 35 (ADC1_CH7), 470k/100k divider, factor 5.7
    analogReadMilliVolts() with 16-sample average, colour-coded status bar
    (green >3.8V, yellow >3.5V, red <=3.5V), refreshed every 10s
    - PING (0x06) / PONG (0x07) ESP-NOW keepalive every 5s
    Transiver replies instantly without UART traffic to ATU
    Disconnect timeout reduced from 60s to 15s (3 missed pings)
    - README updated with new features, protocol table and hardware specs
    [ATU_display.ino, ATU_transiver.ino]
